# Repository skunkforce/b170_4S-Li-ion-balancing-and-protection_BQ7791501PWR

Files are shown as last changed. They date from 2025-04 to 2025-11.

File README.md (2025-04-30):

# edgy_board number b170
This design is part of the [edgy board project](https://github.com/skunkforce/edgy_boards).


# getting started
This repository uses submodules. After cloning use the command 

```$ git submodule update --init --recursive```

to pull the submodules before opening the project with kicad. 

# Tests
Tests can be found in [TESTS.md](TESTS.md)

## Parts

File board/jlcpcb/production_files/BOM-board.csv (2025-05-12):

Comment | Designator | Footprint | LCSC | Quantity
BAS316 | D2 | D_SOD-323 | C109218 | 1
CSD18534Q5A | Q2,Q3 | TDSON-8-1 | C115943 | 2
SMBJ26A-13-F | D3 | D_SMB | C135062 | 1
0.1uF | C18,C19,C20,C21,C22,C26 | C_0603_1608Metric | C14663 | 6
1uF | C11,C12,C13,C14,C15,C16,C17,C23 | C_0603_1608Metric | C15849 | 8
1k | R19,R66,R67,R68,R69 | R_0603_1608Metric | C21190 | 5
100R | R21,R22 | R_0603_1608Metric | C22775 | 2
C3 LED | D10,D11,D12,D9 | LED_0603_1608Metric | C2286 | 4
1M | R27 | R_0603_1608Metric | C22935 | 1
33R | R10,R15,R16,R17,R18 | R_0603_1608Metric | C23140 | 5
3M | R26 | R_0603_1608Metric | C23156 | 1
470k | R28 | R_0603_1608Metric | C23178 | 1
5.1k | R23,R24 | R_0603_1608Metric | C23186 | 2
100k | R29 | R_0603_1608Metric | C25803 | 1
10k | R30,R31,R32 | R_0603_1608Metric | C25804 | 3
BQ7791501PWR | U3 | TSSOP-24_4.4x7.8mm_P0.65mm | C2876946 | 1
15mΩ SHUNT RLP25FEER015 | R20 | R_Shunt_Vishay_WSK2512_6332Metric_T1.19mm | C393085 | 1
10M | R25 | R_0603_1608Metric | C7250 | 1
MMSZ5248B | D1 | D_SOD-123 | C82088 | 1
10uF | C24,C25 | C_0603_1608Metric | C96446 | 2
022_battery_cells | J2 | on_edge_2x05_host |  | 1
022_battery_cells | J1 | on_edge_2x05_device |  | 1
Logo_Open_Hardware_Small | LOGO1 | OSHW-Symbol_6.7x6mm_SilkScreen |  | 1
103AT 10k | TH1 | PinHeader_1x02_P2.54mm_Vertical |  | 1

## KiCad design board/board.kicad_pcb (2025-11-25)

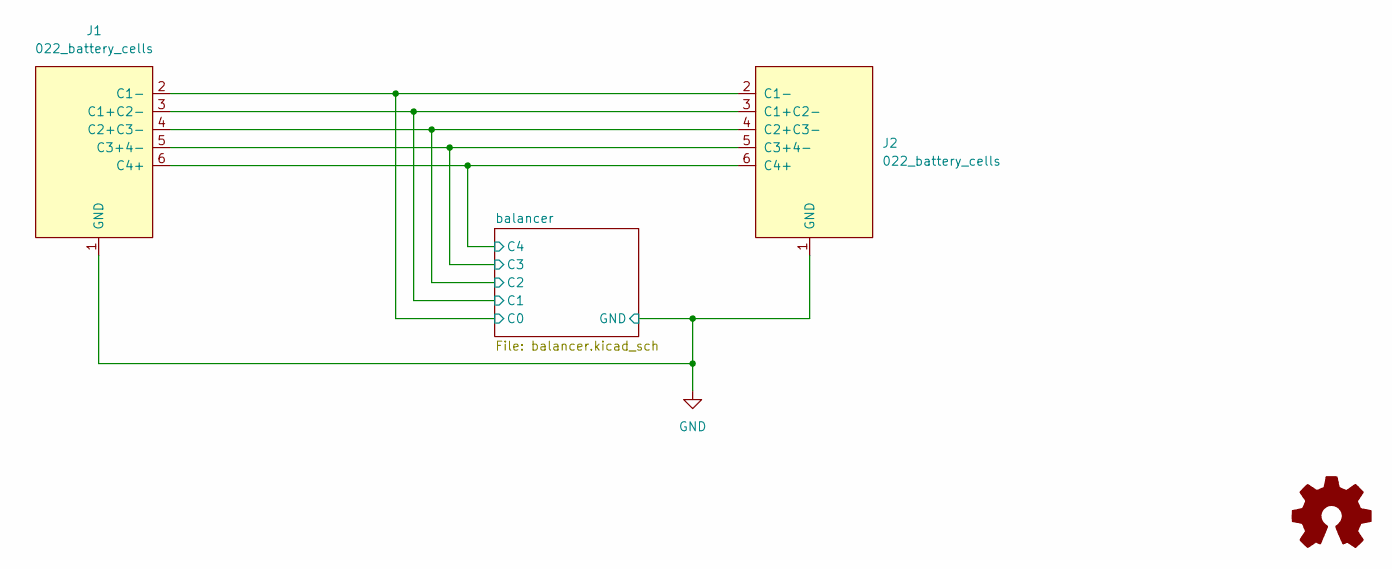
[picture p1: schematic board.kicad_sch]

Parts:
J1: 022_battery_cells; on_edge_2x05_device
J2: 022_battery_cells; on_edge_2x05_host
LOGO1: Logo_Open_Hardware_Small; OSHW-Symbol_6.7x6mm_SilkScreen

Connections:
/balancer/C0: J1.2 (C1-), J2.2 (C1-); also elsewhere on the board
/balancer/C1: J1.3 (C1+C2-), J2.3 (C1+C2-); also elsewhere on the board
/balancer/C2: J1.4 (C2+C3-), J2.4 (C2+C3-); also elsewhere on the board
/balancer/C3: J1.5 (C3+4-), J2.5 (C3+4-); also elsewhere on the board
/balancer/C4: J1.6 (C4+), J2.6 (C4+); also elsewhere on the board
GND: J1.1 (GND), J2.1 (GND); also elsewhere on the board

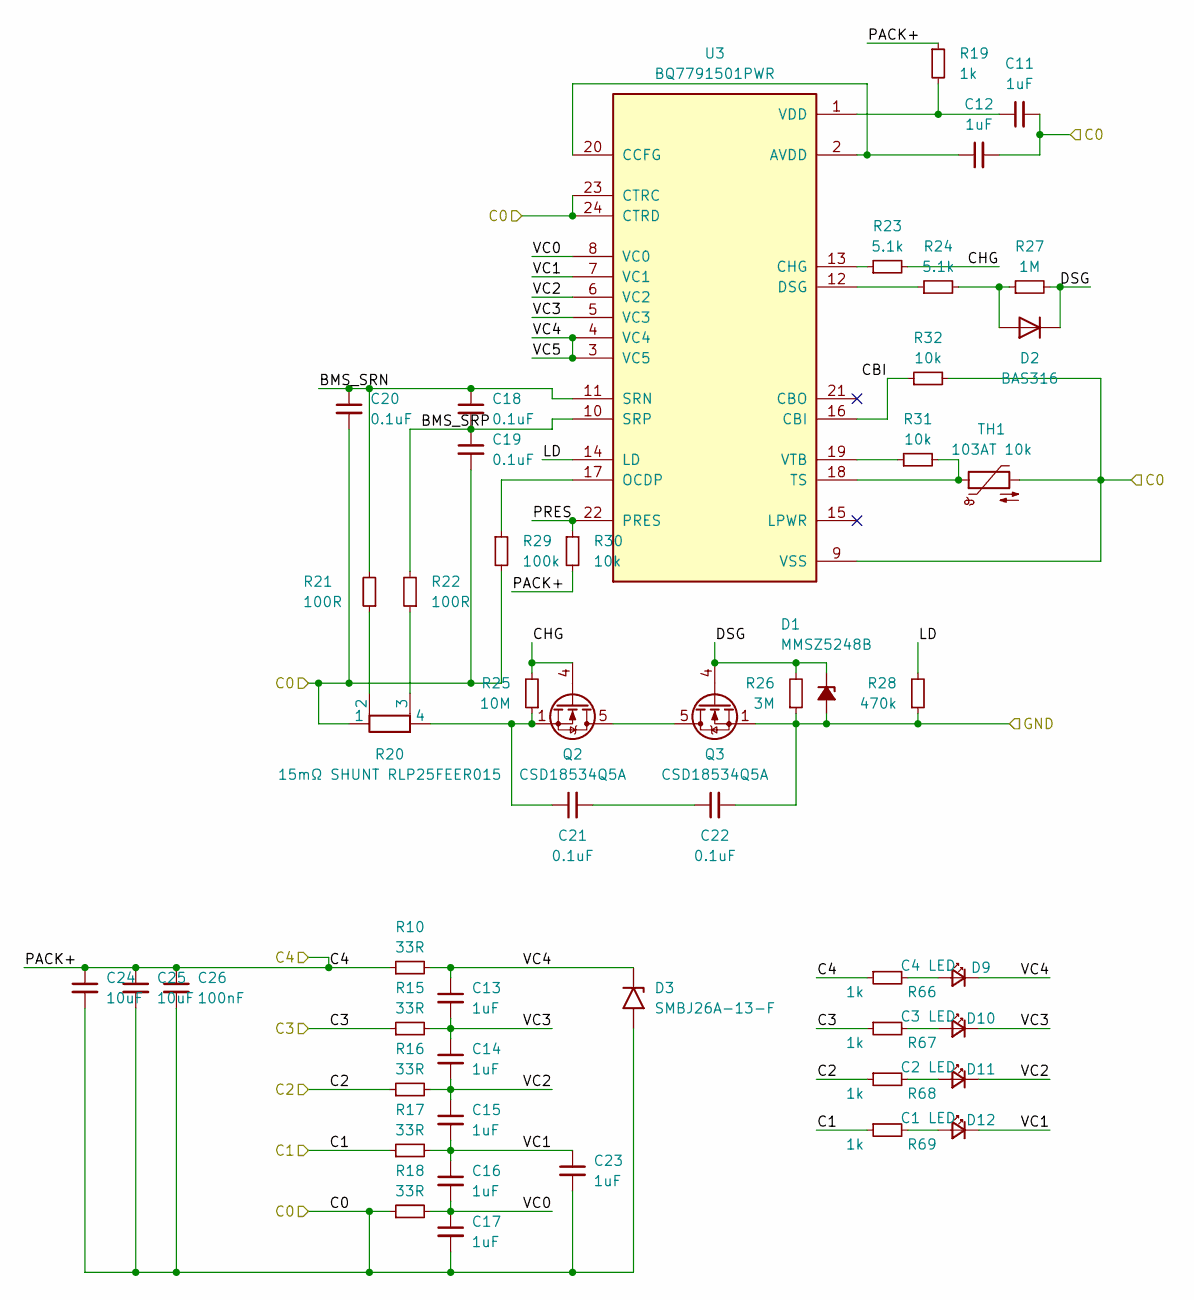
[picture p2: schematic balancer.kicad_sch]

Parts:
C11, C12, C13, C14, C15, C16, C17, C23: 1uF; C_0603_1608Metric; LCSC C15849
C18, C19, C20, C21, C22: 0.1uF; C_0603_1608Metric; LCSC C14663
C24, C25: 10uF; C_0603_1608Metric; LCSC C96446
C26: 100nF; C_0603_1608Metric; LCSC C14663
D1: MMSZ5248B; D_SOD-123; LCSC C82088
D2: BAS316; D_SOD-323; LCSC C109218
D3: SMBJ26A-13-F; D_SMB; LCSC C135062
D9: C4 LED; LED_0603_1608Metric; LCSC C2286
D10: C3 LED; LED_0603_1608Metric; LCSC C2286
D11: C2 LED; LED_0603_1608Metric; LCSC C2286
D12: C1 LED; LED_0603_1608Metric; LCSC C2286
Q2, Q3: CSD18534Q5A; TDSON-8-1; LCSC C115943
R10, R15, R16, R17, R18: 33R; R_0603_1608Metric; LCSC C23140
R19, R66, R67, R68, R69: 1k; R_0603_1608Metric; LCSC C21190
R20: 15mΩ SHUNT RLP25FEER015; R_Shunt_Vishay_WSK2512_6332Metric_T1.19mm; LCSC C393085
R21, R22: 100R; R_0603_1608Metric; LCSC C22775
R23, R24: 5.1k; R_0603_1608Metric; LCSC C23186
R25: 10M; R_0603_1608Metric; LCSC C7250
R26: 3M; R_0603_1608Metric; LCSC C23156
R27: 1M; R_0603_1608Metric; LCSC C22935
R28: 470k; R_0603_1608Metric; LCSC C23178
R29: 100k; R_0603_1608Metric; LCSC C25803
R30, R31, R32: 10k; R_0603_1608Metric; LCSC C25804
TH1: 103AT 10k; PinHeader_1x02_P2.54mm_Vertical
U3: BQ7791501PWR; TSSOP-24_4.4x7.8mm_P0.65mm; PARTREV H; LCSC C2876946

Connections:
/balancer/BMS_SRN: C18.1, C20.1, R21.2, U3.11 (SRN)
/balancer/BMS_SRP: C18.2, C19.1, R22.2, U3.10 (SRP)
/balancer/C0: C11.2, C12.2, C17.2, C19.2, C20.2, C23.2, C24.2, C25.2, C26.2, D3.2 (A2), R18.1, R20.1, R29.2, R32.2, TH1.2, U3.9 (VSS), U3.23 (CTRC), U3.24 (CTRD); also elsewhere on the board
/balancer/C1: R17.1, R69.1; also elsewhere on the board
/balancer/C2: R16.1, R68.1; also elsewhere on the board
/balancer/C3: R15.1, R67.1; also elsewhere on the board
/balancer/C4: C24.1, C25.1, C26.1, R10.1, R19.1, R30.2, R66.1; also elsewhere on the board
/balancer/CBI: R32.1, U3.16 (CBI)
/balancer/CHG: Q2.4 (G), R23.2, R25.2
/balancer/DSG: D1.1 (K), D2.1 (K), Q3.4 (G), R26.2, R27.2
/balancer/LD: R28.2, U3.14 (LD)
/balancer/PRES: R30.1, U3.22 (PRES)
/balancer/VC0: C16.2, C17.1, R18.2, U3.8 (VC0)
/balancer/VC1: C15.2, C16.1, C23.1, D12.1 (K), R17.2, U3.7 (VC1)
/balancer/VC2: C14.2, C15.1, D11.1 (K), R16.2, U3.6 (VC2)
/balancer/VC3: C13.2, C14.1, D10.1 (K), R15.2, U3.5 (VC3)
/balancer/VC4: C13.1, D3.1 (A1), D9.1 (K), R10.2, U3.3 (VC5), U3.4 (VC4)
GND: C22.2, D1.2 (A), Q3.1 (S), Q3.2 (S), Q3.3 (S), R26.1, R28.1; also elsewhere on the board
unnamed: C21.1, Q2.1 (S), Q2.2 (S), Q2.3 (S), R20.4, R25.1
unnamed: C21.2, C22.1
unnamed: D2.2 (A), R24.2, R27.1
unnamed: D9.2 (A), R66.2
unnamed: D10.2 (A), R67.2
unnamed: D11.2 (A), R68.2
unnamed: D12.2 (A), R69.2
unnamed: Q2.5 (D), Q3.5 (D)
unnamed: R20.2, R21.1
unnamed: R20.3, R22.1
unnamed: C12.1, U3.2 (AVDD), U3.20 (CCFG)
unnamed: R23.1, U3.13 (CHG)
unnamed: R24.1, U3.12 (DSG)
unnamed: R29.1, U3.17 (OCDP)
unnamed: R31.2, TH1.1, U3.18 (TS)
unnamed: C11.1, R19.2, U3.1 (VDD)
unnamed: R31.1, U3.19 (VTB)

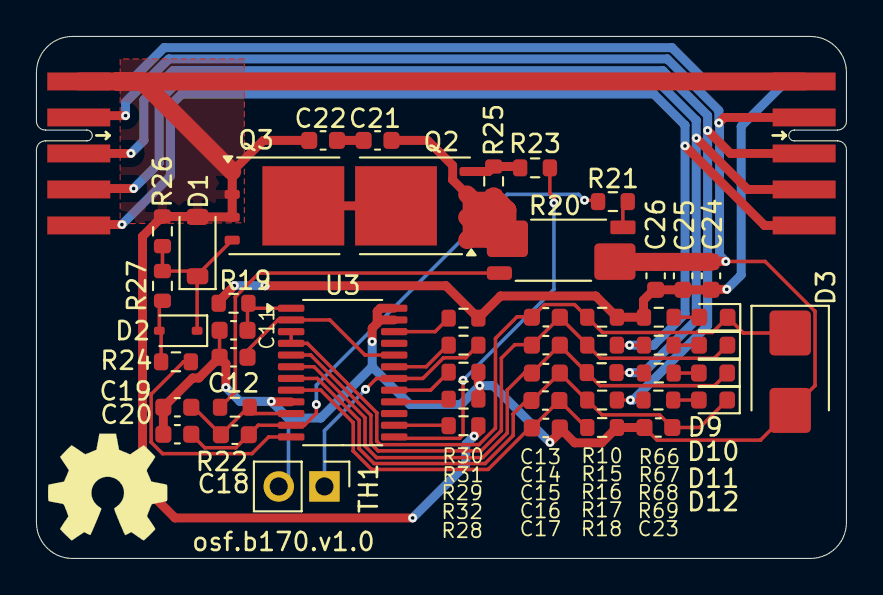
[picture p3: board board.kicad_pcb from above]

Board: 2 copper layers, 45.0 x 29.0 mm, 53 parts (0 on the bottom side), 35 nets.

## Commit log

2025-05-12 added production files
    [BOM-board.csv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]
2025-11-25 added board number on silk screen
    [board.kicad_pcb]
